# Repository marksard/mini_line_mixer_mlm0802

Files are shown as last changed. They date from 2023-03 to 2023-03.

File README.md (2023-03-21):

# Mini Line Mixer MLM0802

'Mini Line Mixer MLM0802' is 100mm x 100mm size audio line level mixer.  
A total of 3ch x2 of mono inputs and 1ch of stereo inupt, 2ch of stereo outputs are provided.  
This is perfect for mixing audio from small instruments.  
It does not have a pan pot, but can be used as a stereo 4-channel mixer.  

[blog](https://marksard.github.io/2023/02/23/make-line-mixer/)

  

  

  

## Specification

### Input

Monoral:  

- 3ch (A line group)  
- 3ch (B line group)  

3.5mm phone jack (TS, Unbaranced)

Stereo:  

- 1ch (Input as Tip to A line group, and as Ring to input B line group)  

3.5mm phone jack (TRS, Unbaranced)  

### Output

Monoral:  

- A output  
- B output  

3.5mm phone jack (TS, Unbaranced)  

Stereo:  

- Monitor output  

3.5mm phone jack (TRS, Unbaranced)  
The user can select A or B outputs for the left and right channels, respectively.  

### Power supply

- 5V to 9V
- MAX 100mA

### Block diagram



### Parts List

|Item|Qty|Reference(s)|Value|Part Model No.|
|:--|:--|:--|:--|:--|
|1|8|C1, C2, C3, C4, C5, C6, C7, C8|1u|サイズ max 5phi x 11mm|
|2|6|C9, C10, C12, C13, C15, C17|22p|セラミック seramic|
|3|2|C11, C14|47u|サイズ max 5phi x 11mm|
|4|2|C16, C18|470u|サイズ max 10phi x 12.5mm|
|5|1|C101|100u|サイズ max 10phi x 12.5mm|
|6|4|C102, C104, C105, C106|100n|積セラ multilayer ceramic|
|7|1|C103|47u|サイズ max 5phi x 11mm|
|8|1|J1|Ach1|マル信 est-marushin MJ-355W|
|9|1|J2|Ach2|マル信 est-marushin MJ-355W|
|10|1|J3|Ach3|マル信 est-marushin MJ-355W|
|11|1|J4|A/Bch4|マル信 est-marushin MJ-355W|
|12|1|J5|Bch1|マル信 est-marushin MJ-355W|
|13|1|J6|Bch2|マル信 est-marushin MJ-355W|
|14|1|J7|Bch3|マル信 est-marushin MJ-355W|
|15|1|J9|A Out|マル信 est-marushin MJ-355W|
|16|1|J10|B Out|マル信 est-marushin MJ-355W|
|17|1|J11|Phone Out|マル信 est-marushin MJ-355W|
|18|1|J101|Center negative|マル信 est-marushin MJ-179P|
|19|4|Q1, Q2, Q3, Q4|2SK170 or 2SK303L|2SK170 or 2SK303L|
|20|12|R1, R2, R3, R4, R5, R6, R7, R8, R12, R18, R22, R27|51k|金属皮膜 metal film 1/4w|
|21|4|R9, R15, R21, R26|1meg|金属皮膜 metal film 1/4w|
|22|4|R10, R11, R16, R17|27k|金属皮膜 metal film 1/4w|
|23|4|R14, R20, R25, R30|10k|金属皮膜 metal film 1/4w|
|24|2|R23, R28|20k|金属皮膜 metal film 1/4w|
|25|1|R101|1.5k|金属皮膜 metal film 1/4w|
|26|2|R102, R103|4.7k|金属皮膜 metal film 1/4w|
|27|6|RV1, RV2, RV3, RV5, RV6, RV7|A10k|ALPS RK09L1140-F15-C0-A103|
|28|1|RV4|A10k|ALPS RK09L1240-F15-C0-A103 2gang (2連)|
|29|2|RV9, RV10|B100k|ALPS RK09L1140-F15-C0-B104|
|30|1|RV11|B50k|ALPS RK09L1240-F15-C0-B503 2gang (2連)|
|31|1|SW1|Lch Selecter|NKK B-12CCPR|
|32|1|SW2|Rch Selecter|NKK B-12CCPR|
|33|1|SW101|Power Sw|NKK B-12CCPR|
|34|1|U1|NJM5532|NJM-5532|
|35|2|U2, U3|NJM5532|NJM-5532|
|36|4|-|-|Both Screw Spacer M3 11mm|
|37|8|-|-|Screw M3 4mm|
|38|4|-|-|Feet|
|39|10|-|Pot Knob|D-type 180digree<br>max outer size phi14mm|
|40|1|-|-|DC Adapter 9V 100mA Center negative, 2.1mm/5.5mm Jack|

### PCB image

PCB image

### Schematic

Schematic

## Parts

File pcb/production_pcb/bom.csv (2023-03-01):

Designator | Footprint | Quantity | Value | LCSC Part #
C1, C2, C3, C4, C5, C6, C7, C8 | Capacitor_THT_5x11_Holizontal | 8 | 1u
C10, C12, C13, C15, C17, C9 | C_Disc_D4.7mm_W2.5mm_P5.00mm | 6 | 22p
C101 | Capacitor_THT_10x12.5_Holizontal | 1 | 100u
C102, C104, C105, C106 | Capacitor_THT_2.5_3.6_Ceramic | 4 | 100n
C103, C11, C14 | Capacitor_THT_5x11_Holizontal | 3 | 47u
C16, C18 | Capacitor_THT_10x12.5_Holizontal | 2 | 470u
H1 | MiniLineMixer_PCB_v1.0.0 | 1 | Marksard_Audio:MiniLineMixer_PCB_v1.0.0
H2, H3 | marksard_logo | 2 | Marksard Logo
J1 | MJ-355W | 1 | Ach1
J10 | MJ-355W | 1 | B Out
J101 | MJ-179P | 1 | Center -
J11 | MJ-355W | 1 | Phone Out
J2 | MJ-355W | 1 | Ach2
J3 | MJ-355W | 1 | Ach3
J4 | MJ-355W | 1 | A/Bch4
J5 | MJ-355W | 1 | Bch1
J6 | MJ-355W | 1 | Bch2
J7 | MJ-355W | 1 | Bch3
J9 | MJ-355W | 1 | A Out
Q1, Q2, Q3, Q4 | TO-92_K170-303L | 4 | 2SK170 or 2SK303L
R1, R12, R18, R2, R22, R27, R3, R4, R5, R6, R7, R8 | R_Axial_DIN0204_L3.6mm_D1.6mm_P2.54mm_Vertical | 12 | 51k
R10, R11, R16, R17 | R_Axial_DIN0204_L3.6mm_D1.6mm_P2.54mm_Vertical | 4 | 27k
R101 | R_Axial_DIN0204_L3.6mm_D1.6mm_P2.54mm_Vertical | 1 | 1.5k
R102, R103 | R_Axial_DIN0204_L3.6mm_D1.6mm_P2.54mm_Vertical | 2 | 4.7k
R14, R20, R25, R30 | R_Axial_DIN0204_L3.6mm_D1.6mm_P2.54mm_Vertical | 4 | 10k
R15, R21, R26, R9 | R_Axial_DIN0204_L3.6mm_D1.6mm_P2.54mm_Vertical | 4 | 1meg
R23, R28 | R_Axial_DIN0204_L3.6mm_D1.6mm_P2.54mm_Vertical | 2 | 20k
RV1, RV2, RV3, RV5, RV6, RV7 | Potentiometer_THT_RK09L1140 | 6 | A10k
RV10, RV9 | Potentiometer_THT_RK09L1140 | 2 | B100k
RV11 | Potentiometer_THT_RK09L1240 | 1 | B50k
RV4 | Potentiometer_THT_RK09L1240 | 1 | A10k
SW1 | B-12CCPR | 1 | Lch Selecter
SW101 | B-12CCPR | 1 | Power Sw
SW2 | B-12CCPR | 1 | Rch Selecter
TP1 | TestPoint_THTPad_D1.5mm_Drill0.7mm | 1 | VCC
TP2 | TestPoint_THTPad_D1.5mm_Drill0.7mm | 1 | GND
U1, U2, U3 | DIP-8_W7.62mm_Socket | 3 | NJM5532

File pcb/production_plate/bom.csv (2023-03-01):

Designator | Footprint | Quantity | Value | LCSC Part #
H1 | MiniLineMixer_Plate_v1.0.0 | 1 | Marksard_Audio:MiniLineMixer_Plate_v1.0.0

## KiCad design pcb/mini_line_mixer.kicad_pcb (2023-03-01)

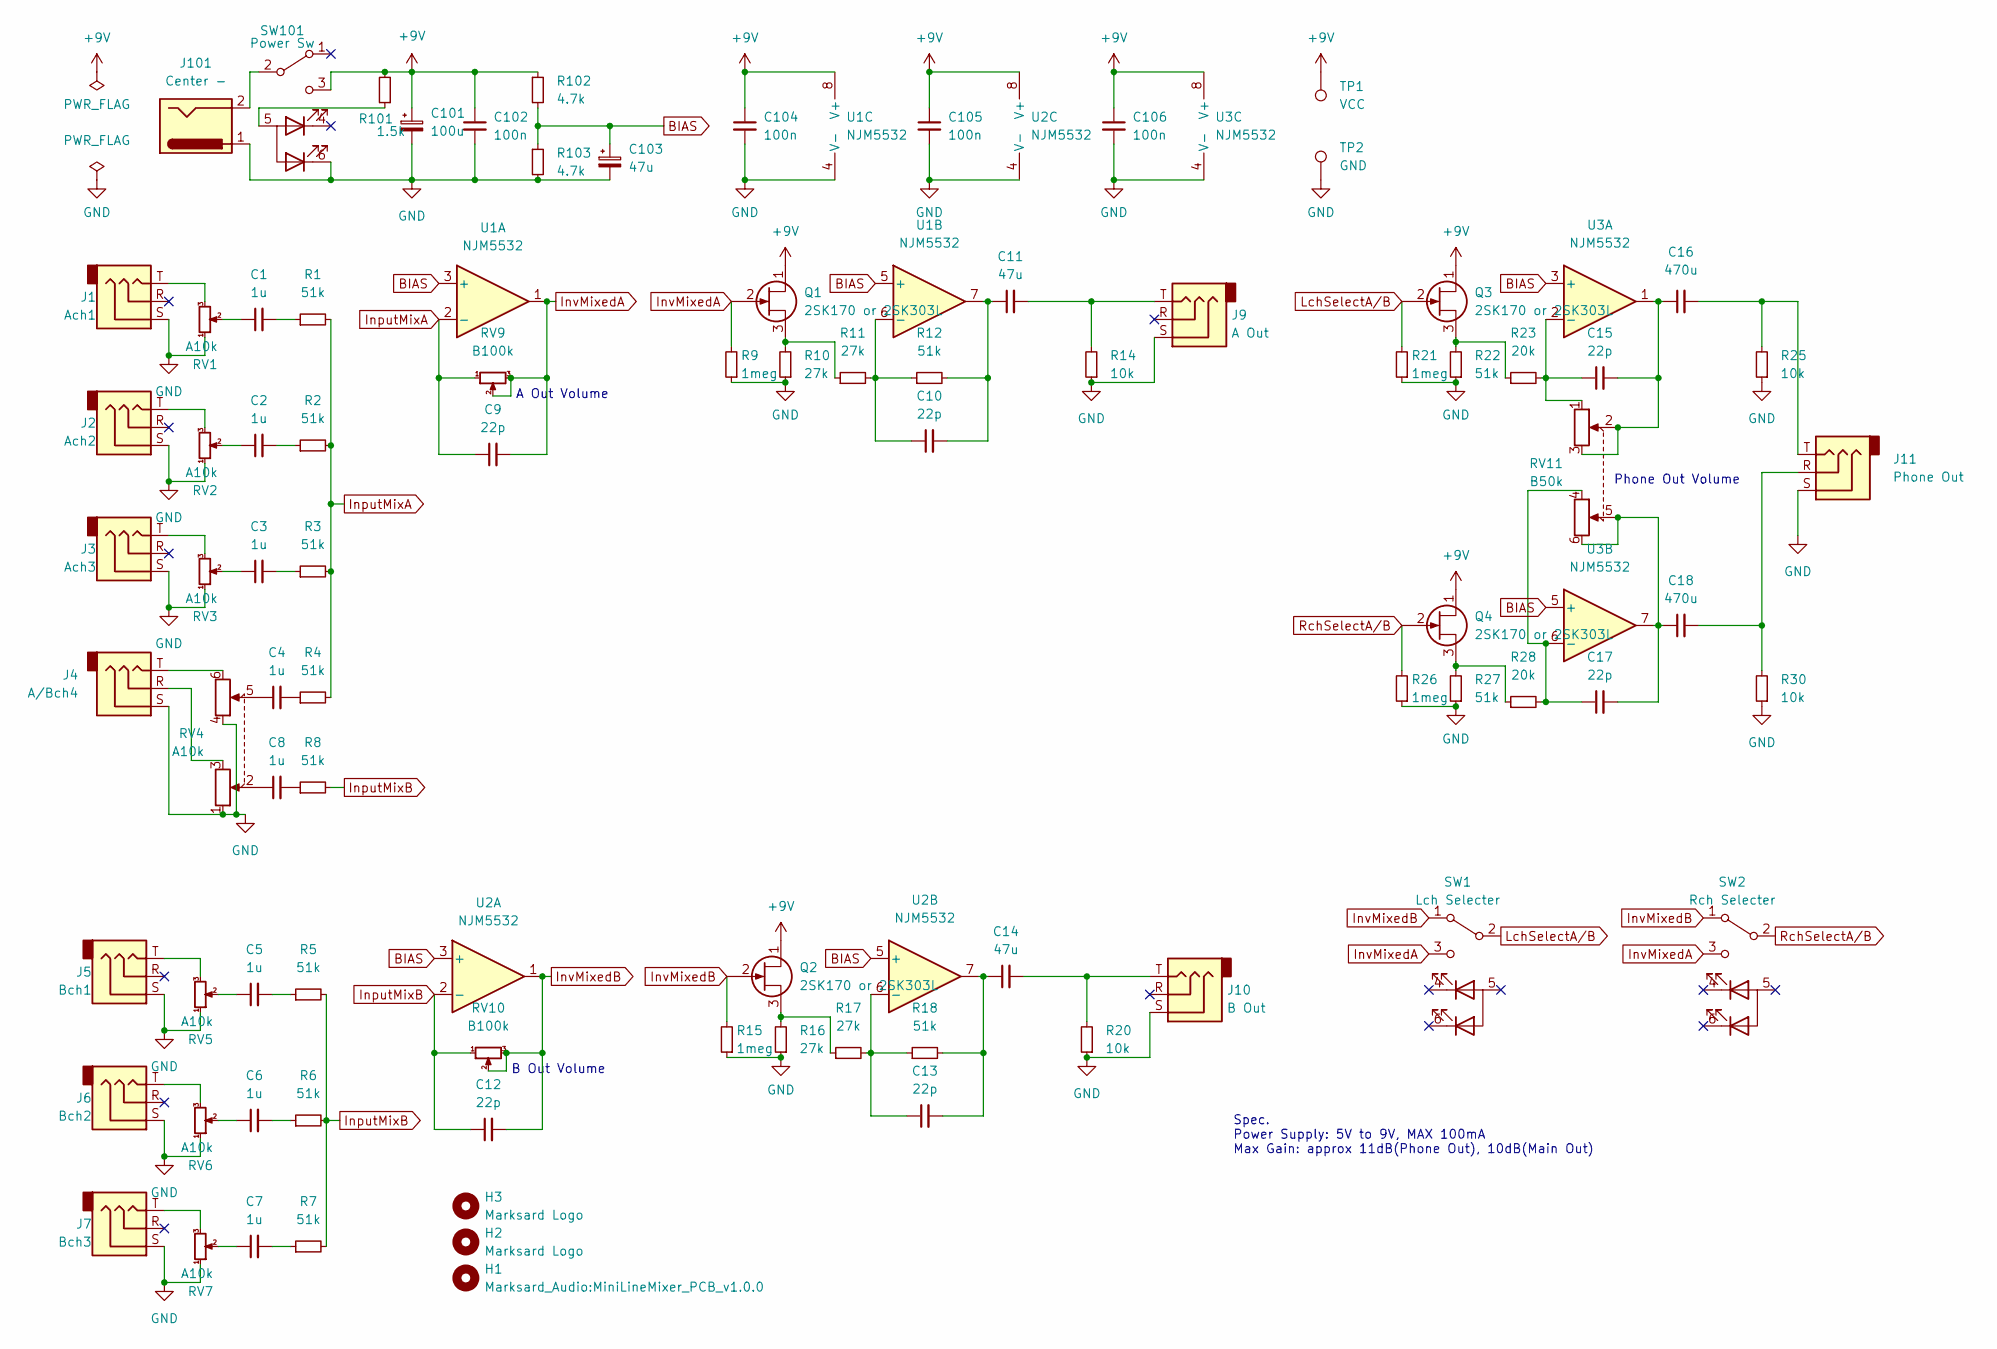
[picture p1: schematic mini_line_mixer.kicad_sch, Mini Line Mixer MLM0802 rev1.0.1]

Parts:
C1, C2, C3, C4, C5, C6, C7, C8: 1u; Capacitor_THT_5x11_Holizontal; Part Model No. サイズ max 5phi x 11mmまで
C9, C10, C12, C13, C15, C17: 22p; C_Disc_D4.7mm_W2.5mm_P5.00mm; Part Model No. セラミック seramic
C11, C14, C103: 47u; Capacitor_THT_5x11_Holizontal; Part Model No. サイズ max 5phi x 11mmまで
C16, C18: 470u; Capacitor_THT_10x12.5_Holizontal; Part Model No. サイズ max 10phi x 12.5mm
C101: 100u; Capacitor_THT_10x12.5_Holizontal; Part Model No. サイズ max 10phi x 12.5mm
C102, C104, C105, C106: 100n; Capacitor_THT_2.5_3.6_Ceramic; Part Model No. 積セラ multilayer ceramic
H1: Marksard_Audio:MiniLineMixer_PCB_v1.0.0; MiniLineMixer_PCB_v1.0.0
H2, H3: Marksard Logo; marksard_logo
J1: Ach1; MJ-355W; Part Model No. マル信 est-marushin MJ-355W
J2: Ach2; MJ-355W; Part Model No. マル信 est-marushin MJ-355W
J3: Ach3; MJ-355W; Part Model No. マル信 est-marushin MJ-355W
J4: A/Bch4; MJ-355W; Part Model No. マル信 est-marushin MJ-355W
J5: Bch1; MJ-355W; Part Model No. マル信 est-marushin MJ-355W
J6: Bch2; MJ-355W; Part Model No. マル信 est-marushin MJ-355W
J7: Bch3; MJ-355W; Part Model No. マル信 est-marushin MJ-355W
J9: A Out; MJ-355W; Part Model No. マル信 est-marushin MJ-355W
J10: B Out; MJ-355W; Part Model No. マル信 est-marushin MJ-355W
J11: Phone Out; MJ-355W; Part Model No. マル信 est-marushin MJ-355W
J101: Center -; MJ-179P; Part Model No. マル信 est-marushin MJ-179P
Q1, Q2, Q3, Q4: 2SK170 or 2SK303L; TO-92_K170-303L; Part Model No. 2SK170 or 2SK303L
R1, R2, R3, R4, R5, R6, R7, R8, R12, R18, R22, R27: 51k; R_Axial_DIN0204_L3.6mm_D1.6mm_P2.54mm_Vertical; Part Model No. 金属皮膜 metal film 1/4w
R9, R15, R21, R26: 1meg; R_Axial_DIN0204_L3.6mm_D1.6mm_P2.54mm_Vertical; Part Model No. 金属皮膜 metal film 1/4w
R10, R11, R16, R17: 27k; R_Axial_DIN0204_L3.6mm_D1.6mm_P2.54mm_Vertical; Part Model No. 金属皮膜 metal film 1/4w
R14, R20, R25, R30: 10k; R_Axial_DIN0204_L3.6mm_D1.6mm_P2.54mm_Vertical; Part Model No. 金属皮膜 metal film 1/4w
R23, R28: 20k; R_Axial_DIN0204_L3.6mm_D1.6mm_P2.54mm_Vertical; Part Model No. 金属皮膜 metal film 1/4w
R101: 1.5k; R_Axial_DIN0204_L3.6mm_D1.6mm_P2.54mm_Vertical; Part Model No. 金属皮膜 metal film 1/4w
R102, R103: 4.7k; R_Axial_DIN0204_L3.6mm_D1.6mm_P2.54mm_Vertical; Part Model No. 金属皮膜 metal film 1/4w
RV1, RV2, RV3, RV5, RV6, RV7: A10k; Potentiometer_THT_RK09L1140; Part Model No. ALPS RK09L1140-F15-C0-A103
RV4: A10k; Potentiometer_THT_RK09L1240; Part Model No. ALPS RK09L1240-F15-C0-A103(2連)
RV9, RV10: B100k; Potentiometer_THT_RK09L1140; Part Model No. ALPS RK09L1140-F15-C0-B104
RV11: B50k; Potentiometer_THT_RK09L1240; Part Model No. ALPS RK09L1240-F15-C0-B503(2連)
SW1: Lch Selecter; B-12CCPR; Part Model No. NKK B-12CCPR
SW2: Rch Selecter; B-12CCPR; Part Model No. NKK B-12CCPR
SW101: Power Sw; B-12CCPR; Part Model No. NKK B-12CCPRM
TP1: VCC; TestPoint_THTPad_D1.5mm_Drill0.7mm
TP2: GND; TestPoint_THTPad_D1.5mm_Drill0.7mm
U1, U2, U3: NJM5532; DIP-8_W7.62mm_Socket; Part Model No. NJM-5532

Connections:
+9V: C101.1, C102.1, C104.1, C105.1, C106.1, Q1.1 (D), Q2.1 (D), Q3.1 (D), Q4.1 (D), R101.2, R102.1, SW101.3 (C), TP1.1, U1.8 (V+), U2.8 (V+), U3.8 (V+)
BIAS: C103.1, R102.2, R103.1, U1.3 (+), U1.5 (+), U2.3 (+), U2.5 (+), U3.3 (+), U3.5 (+)
GND: C101.2, C102.2, C103.2, C104.2, C105.2, C106.2, J1.S, J2.S, J3.S, J4.S, J5.S, J6.S, J7.S, J9.S, J10.S, J11.S, J101.1, R9.1, R10.1, R14.1, R15.1, R16.1, R20.1, R21.1, R22.1, R25.1, R26.1, R27.1, R30.1, R103.2, RV1.1, RV1.MP, RV2.1, RV2.MP, RV3.1, RV3.MP, RV4.1, RV4.4, RV4.MP, RV5.1, RV5.MP, RV6.1, RV6.MP, RV7.1, RV7.MP, RV9.MP, RV10.MP, RV11.MP, SW101.6 (F), TP2.1, U1.4 (V-), U2.4 (V-), U3.4 (V-)
InputMixA: C9.1, R1.2, R2.2, R3.2, R4.2, RV9.1, U1.2 (-)
InputMixB: C12.1, R5.2, R6.2, R7.2, R8.2, RV10.1, U2.2 (-)
InvMixedA: C9.2, Q1.2 (G), R9.2, RV9.2, RV9.3, SW1.3 (C), SW2.3 (C), U1.1
InvMixedB: C12.2, Q2.2 (G), R15.2, RV10.2, RV10.3, SW1.1 (A), SW2.1 (A), U2.1
LchSelectA/B: Q3.2 (G), R21.2, SW1.2 (B)
unnamed: C1.1, RV1.2
unnamed: C1.2, R1.1
unnamed: C2.1, RV2.2
unnamed: C2.2, R2.1
unnamed: C3.1, RV3.2
unnamed: C3.2, R3.1
unnamed: C4.1, RV4.5
unnamed: C4.2, R4.1
unnamed: C5.1, RV5.2
unnamed: C5.2, R5.1
unnamed: C6.1, RV6.2
unnamed: C6.2, R6.1
unnamed: C7.1, RV7.2
unnamed: C7.2, R7.1
unnamed: C8.1, RV4.2
unnamed: C8.2, R8.1
unnamed: C10.1, R11.2, R12.1, U1.6 (-)
unnamed: C10.2, C11.1, R12.2, U1.7
unnamed: C11.2, J9.T, R14.2
unnamed: C13.1, R17.2, R18.1, U2.6 (-)
unnamed: C13.2, C14.1, R18.2, U2.7
unnamed: C14.2, J10.T, R20.2
unnamed: C15.1, R23.2, RV11.1, U3.2 (-)
unnamed: C15.2, C16.1, RV11.2, RV11.3, U3.1
unnamed: C16.2, J11.T, R25.2
unnamed: C17.1, R28.2, RV11.4, U3.6 (-)
unnamed: C17.2, C18.1, RV11.5, RV11.6, U3.7
unnamed: C18.2, J11.R, R30.2
unnamed: J1.T, RV1.3
unnamed: J2.T, RV2.3
unnamed: J3.T, RV3.3
unnamed: J4.R, RV4.3
unnamed: J4.T, RV4.6
unnamed: J5.T, RV5.3
unnamed: J6.T, RV6.3
unnamed: J7.T, RV7.3
unnamed: J101.2, SW101.2 (B)
unnamed: Q1.3 (S), R10.2, R11.1
unnamed: Q2.3 (S), R16.2, R17.1
unnamed: Q3.3 (S), R22.2, R23.1
unnamed: Q4.3 (S), R27.2, R28.1
unnamed: R101.1, SW101.5 (E)
RchSelectA/B: Q4.2 (G), R26.2, SW2.2 (B)

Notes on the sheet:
Phone Out Volume
A Out Volume
B Out Volume
Spec. Power Supply: 5V to 9V, MAX 100mA Max Gain: approx 11dB(Phone Out), 10dB(Main Out)

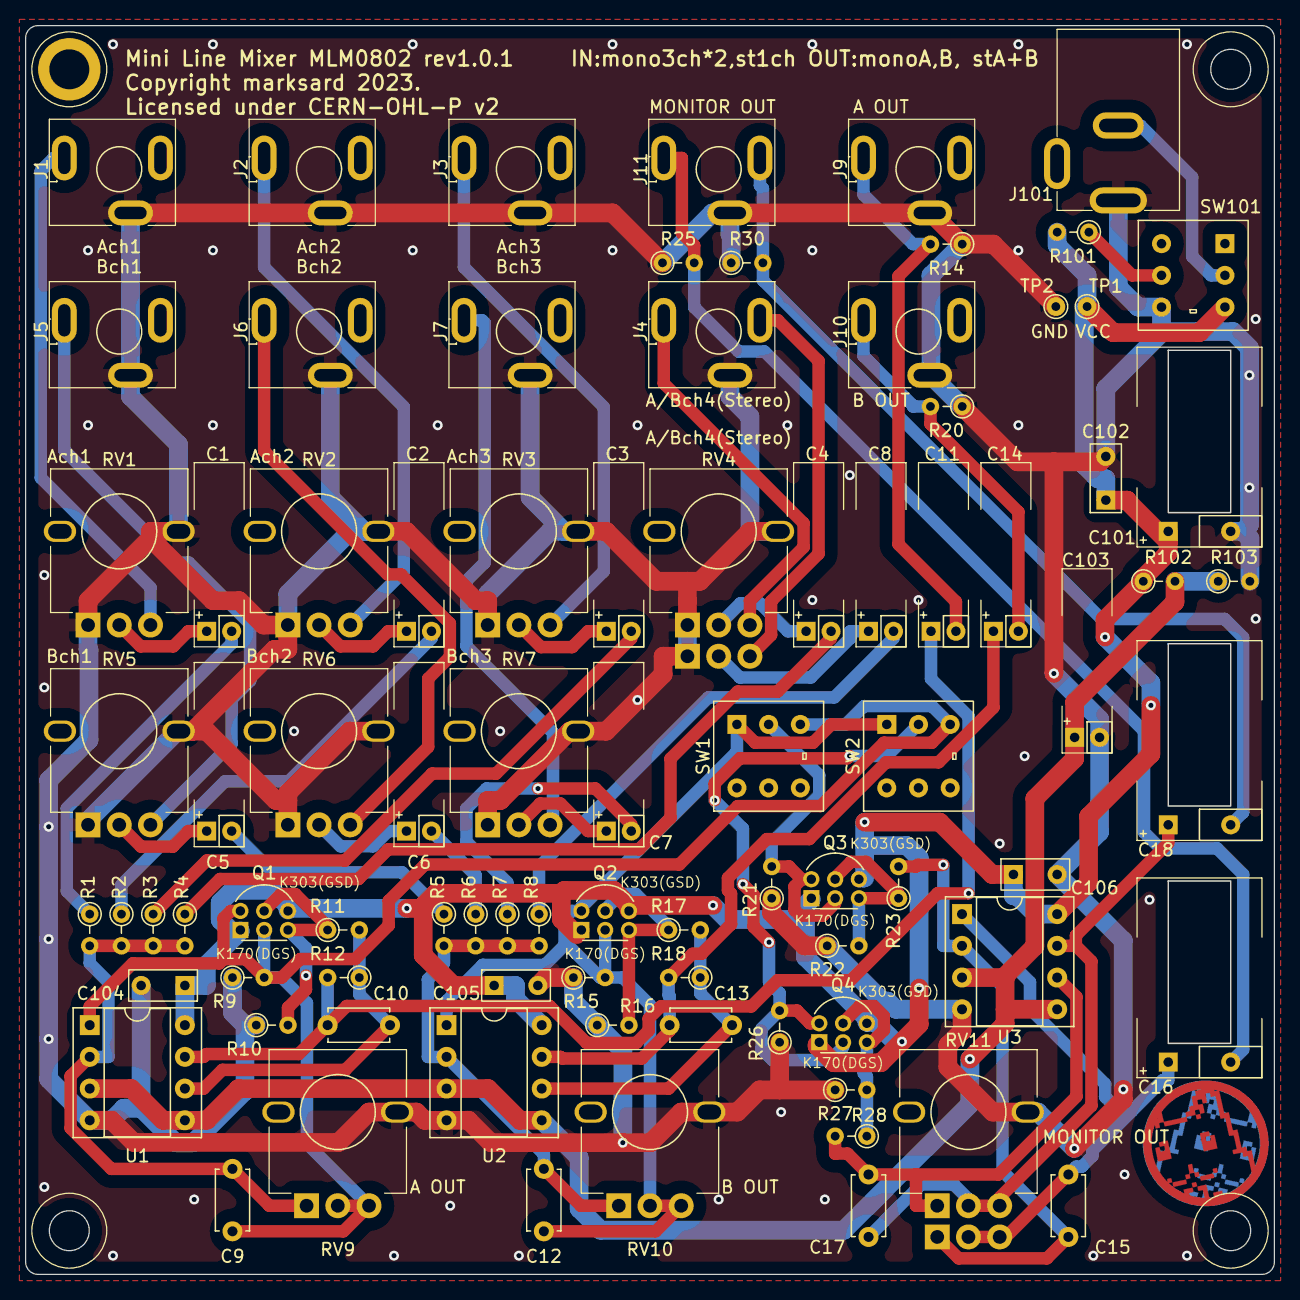
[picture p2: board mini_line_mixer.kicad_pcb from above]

Board: 2 copper layers, 100.0 x 100.0 mm, 89 parts (1 on the bottom side), 51 nets.

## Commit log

2023-03-01 first time
    [bom.csv, designators.csv, mini_line_mixer.csv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]
2023-03-02 move folder
    [bom.csv, designators.csv, mini_line_mixer.csv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]
2023-03-02 Fixed parts discription
    [mini_line_mixer.csv, mini_line_mixer.kicad_sch]

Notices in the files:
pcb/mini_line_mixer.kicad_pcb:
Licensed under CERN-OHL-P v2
